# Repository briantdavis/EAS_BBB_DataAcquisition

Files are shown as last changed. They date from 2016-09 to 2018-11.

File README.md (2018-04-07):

# EagleAeroSport BeagleBone Black
# Data Acquisition System

This REPO is intended to be extracted into the folder /EAS on the beaglebone black.

Contains code C++ compiled directly on the BBB, using the debian GCC tool chain.

Key files:<br>
PCA9544 - I2C Mux<br>
ADXL345 - I2C 3-axis Accelerometer<br>
BME280  - I2C Pressure, Humidity & Temperature<br>
MPU6050 - I2C 3-axis Accelerometer & 3-axis Gyro<br>
hscPress- AMSYS AMS59xx series pressure sensors<br>

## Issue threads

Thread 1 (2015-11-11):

Improve Timestamp

briantdavis, 2015-11-11:
The current Timestamp is very coarse timing - using the clock_t structure & clock() function.
Improve the timestamp - sample code from NCAR capstone project.

jcstrang-edu, 2016-02-04:
I didnt see any obvious time reference in the code, so I made a pull with a small file that gets realtime in nanoseconds.

(See Pull Request)

I cannot tell if it will be anyfaster than the "clock_t structure & clock() fucntion", but I m hopeful none the less

My device reads about 3 microSeconds per loop. (doing nothing else)

jcstrang-edu, 2016-02-08:
As we discussed, we will want to look into the specifics of the "CLOCK_REALTIME" and "CLOCK_MONOTIME" System variable to assess which is more practical for our application.

I wrote a very dirty test script to gather the maximum, minimum, and averages for both calls.
What I see is that they're largely the same having a maximum value of 1 second to a minimum of -1 second. I'm not sure if that is simply the nature of the clock or if that is an error on my part, we can look at it in greater detail at the next meeting.

briantdavis, 2016-02-10:
A dual timestamp is implemented in commit #53.

The output in daqPack >> operator is still not human readable.

Hopefully a single timestamp option will prove functional & reduce computation / jitter.

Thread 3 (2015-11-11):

Calibration

briantdavis, 2015-11-11:
Currently, for many sensors, raw values are reported.
There are commonly calibration values provided with sensors; at this point the known issues are

MPU6050 - Temperature, Accel & Gyro
BMP180 - Temperature & Pressure
HSC Press - Pressure & Temperature

These can be addressed incrementally & in parallel.

ee-eas-erau, 2017-11-13:
Can the calibration be in part a of the file with the information formatted as

Calibration coefficient : {DATA}

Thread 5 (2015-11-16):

I2C operating at 400KHz

briantdavis, 2015-11-16:
It is desirable to have both I2C busses operating at 400kHz.

I have been able to get I2C2 operating at 400kHz, but I need to document how this was done so as not to forget.

I have been unable to get I2C1 operating faster than 100kHz - this is an open issue.

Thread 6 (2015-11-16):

Run scripts automatically at boot time

briantdavis, 2015-11-16:
At the moment I need to run the "Enable_i2c" script as root each time I power-on the BBB to enable I2C2.

It would be advantageous to develop a location / script which is automatically executed as root upon power-on so that we can (for now) configure the board, for example Enable I2C2.

Eventually, we will want the DAQ application to automatically run upon power-up, so this will be essential for the flying article.

jcstrang-edu, 2016-02-04:
I have successfully run some test initalization scripts, please see the most recent pull request.

As of now, It does no more than stated.

I have verified its functionality through a boot, however please note that I do not manage any possible errors during initialization.

I imagine that I could get the "Enable I2C" script working for the next commit.

jcstrang-edu, 2016-02-05:
The script now searches for and runs "Enable_third_i2c.sh"

However, I recently noticed that this script actually executes during startup AND shutdown which could be bad in its current form. I have started looking into it, but I may have some trouble understanding it.

jcstrang-edu, 2016-02-06:
So, the entire issue was the fact that I had a bad directory call in my init script, for details, see pull request 12.

It should work as intended.

It doesn't handle errors, but is that a concern with init scripts?

testenv to be deleted next commit

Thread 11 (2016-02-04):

Auto-Detecting Sensors

jcstrang-edu, 2016-02-04:
As discussed, we want a script that can automatically detect, identify and connect to any attached sensors.

This requires the names (OR a data sheet link!) of every device we plan on connecting to the BBB 4G.

briantdavis, 2016-02-04:
Does not need to be a "script" - I was envisioning this as a component / function within the data acquisition executable.  Could be done either way, but I think it would be easier as a single executable to maintain the data structures.

I have an Exel file (also on T: drive) which lists MOST of the I2C addresses that the auto-detect would be required to identify.  I think the best way to identify the sensors is not by name, but by I2C address.

jcstrang-edu, 2016-02-08:
I will look into it. I can see a slight issue when it comes to auto instantiating, which lies in the fact that I enable the third I2c before anything else in the boot script. I am not entirely sure if enabling the I2c communication will inhibit our ability to use those pins for other IO functions. If it doesn't inhibit anything, then there should be no issues coding an sensor auto-detector (that I foresee).

jcstrang-edu, 2016-02-09:
As discussed in the meeting during Feb 8th, 2016,

The Enable 3rd I2c script will need to be run prior to any sensor auto detect code.

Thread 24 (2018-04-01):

hscpress Sensor Data does not match current log files on network drive

Marsfan, 2018-04-01:
The HSC Press sensor is listed in the eas_daq_pack.h file as being a struct with one u8int_t and two u16int_t variables, for a total of 5 bytes

However, examination of the provided log files shows data that totals 6 bytes. An example of this is the first packet, which is listed as having a data section comprising of '00 00 48 31 DF 02'

The log files were likely made with a different version of the source code. Could I get some information regarding this, confirming the correct file size?

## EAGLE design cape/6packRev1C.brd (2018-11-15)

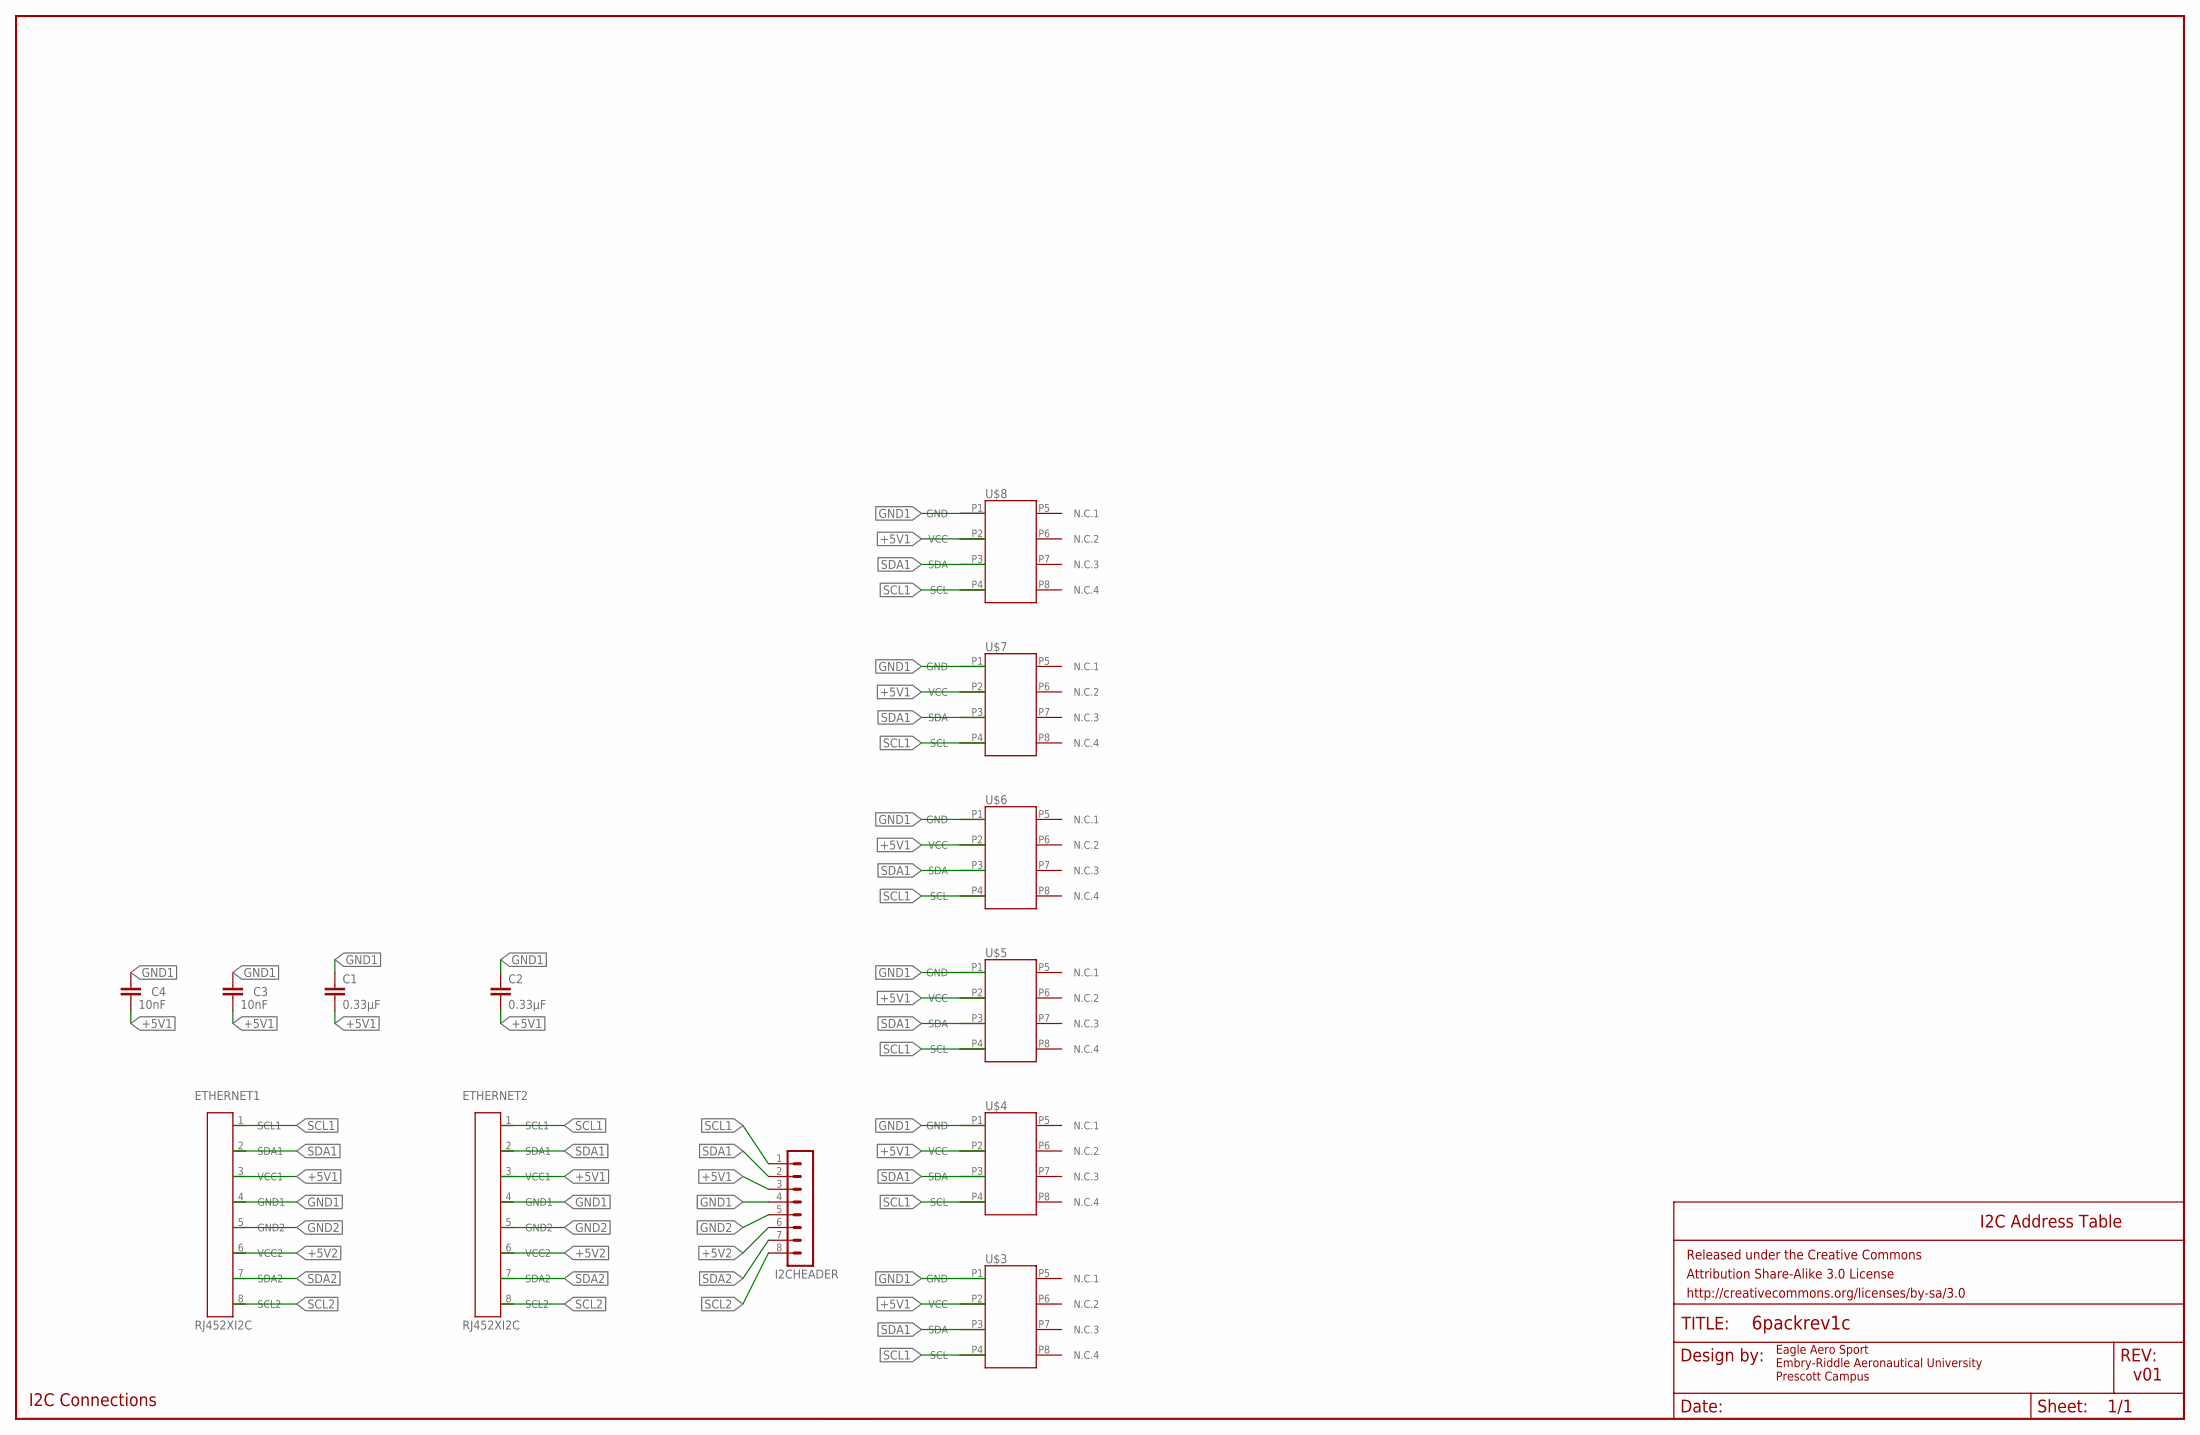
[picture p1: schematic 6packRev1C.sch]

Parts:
C1, C2: 0.33µF; 0805
C3, C4: 10nF; CAP-PTH-10MM
ETHERNET1, ETHERNET2: RJ452XI2C; RJ45-8
FRAME1: FRAME-LEDGER; CREATIVE_COMMONS
I2CHEADER: MA08-1
U$3, U$4, U$5, U$6, U$7, U$8: AMS5915; DIP8W

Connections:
+5V1: C1.2, C2.2, C3.2, C4.2, ETHERNET1.3 (VCC1), ETHERNET2.3 (VCC1), I2CHEADER.3, U$3.P2 (VCC), U$4.P2 (VCC), U$5.P2 (VCC), U$6.P2 (VCC), U$7.P2 (VCC), U$8.P2 (VCC)
+5V2: ETHERNET1.6 (VCC2), ETHERNET2.6 (VCC2), I2CHEADER.6
GND1: C1.1, C2.1, C3.1, C4.1, ETHERNET1.4 (GND1), ETHERNET2.4 (GND1), I2CHEADER.4, U$3.P1 (GND), U$4.P1 (GND), U$5.P1 (GND), U$6.P1 (GND), U$7.P1 (GND), U$8.P1 (GND)
GND2: ETHERNET1.5 (GND2), ETHERNET2.5 (GND2), I2CHEADER.5
SCL1: ETHERNET1.1 (SCL1), ETHERNET2.1 (SCL1), I2CHEADER.1, U$3.P4 (SCL), U$4.P4 (SCL), U$5.P4 (SCL), U$6.P4 (SCL), U$7.P4 (SCL), U$8.P4 (SCL)
SCL2: ETHERNET1.8 (SCL2), ETHERNET2.8 (SCL2), I2CHEADER.8
SDA1: ETHERNET1.2 (SDA1), ETHERNET2.2 (SDA1), I2CHEADER.2, U$3.P3 (SDA), U$4.P3 (SDA), U$5.P3 (SDA), U$6.P3 (SDA), U$7.P3 (SDA), U$8.P3 (SDA)
SDA2: ETHERNET1.7 (SDA2), ETHERNET2.7 (SDA2), I2CHEADER.7

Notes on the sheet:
I2C Address Table
v01
Eagle Aero Sport Embry-Riddle Aeronautical University Prescott Campus
I2C Connections

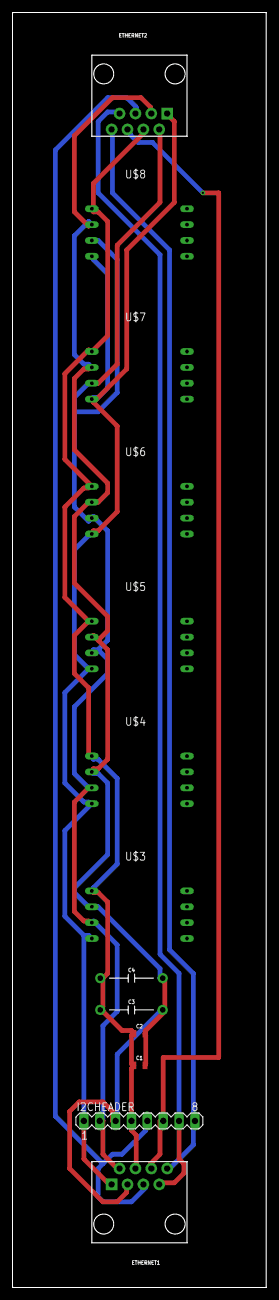
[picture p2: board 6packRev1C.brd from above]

Board: 2 copper layers, 40.6 x 204.1 mm, 14 parts (0 on the bottom side), 8 nets.

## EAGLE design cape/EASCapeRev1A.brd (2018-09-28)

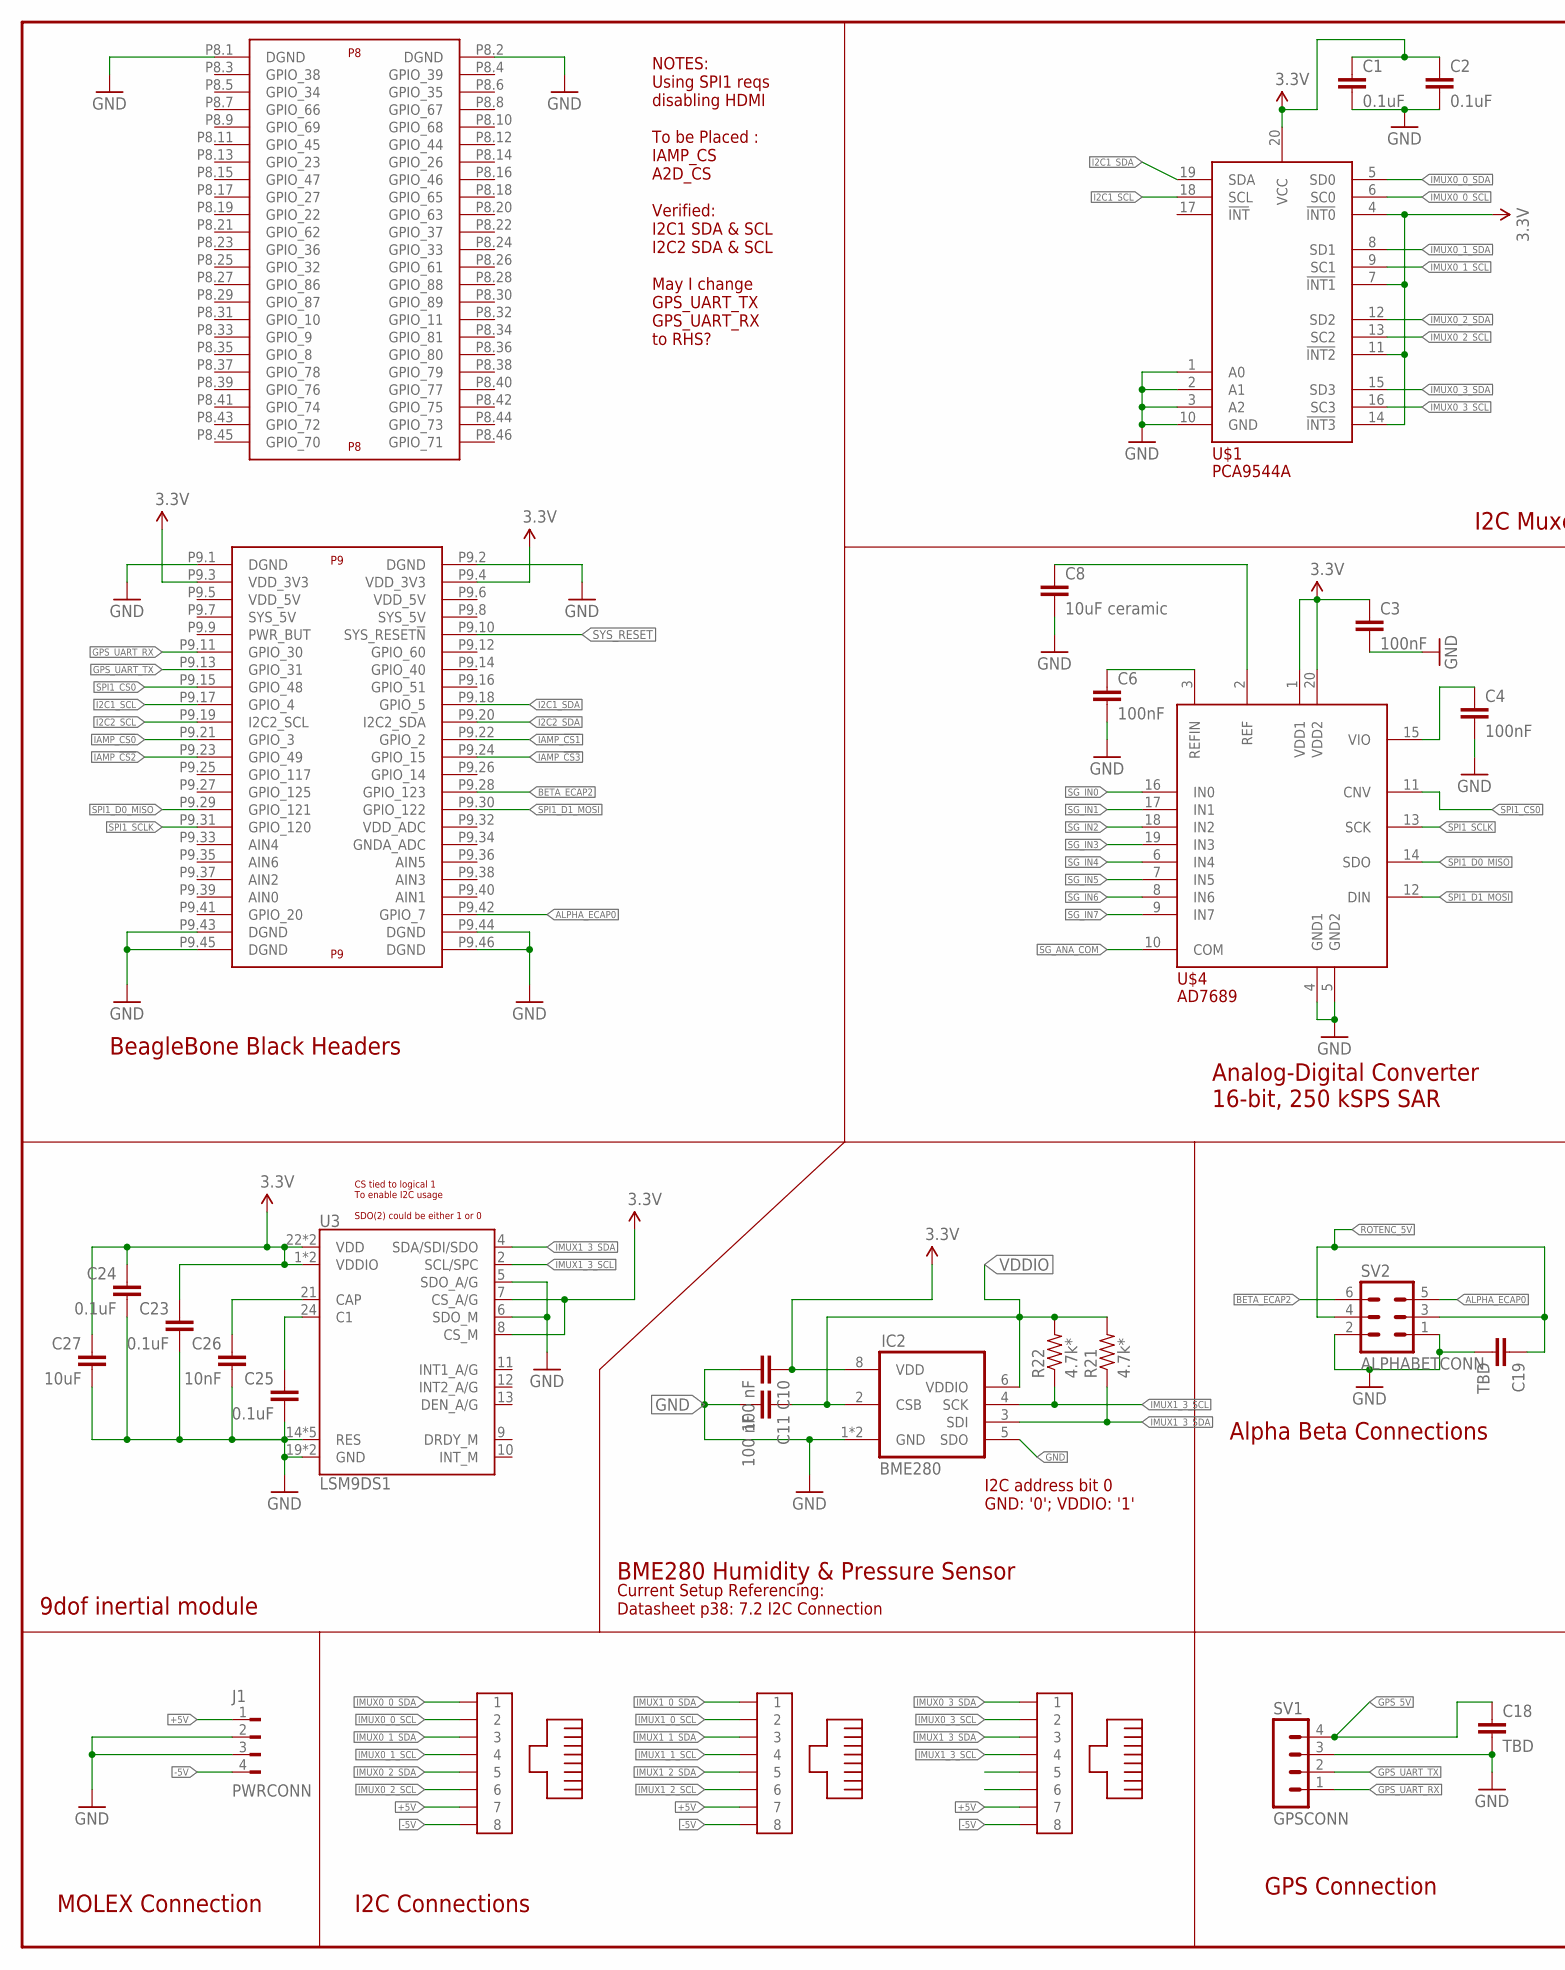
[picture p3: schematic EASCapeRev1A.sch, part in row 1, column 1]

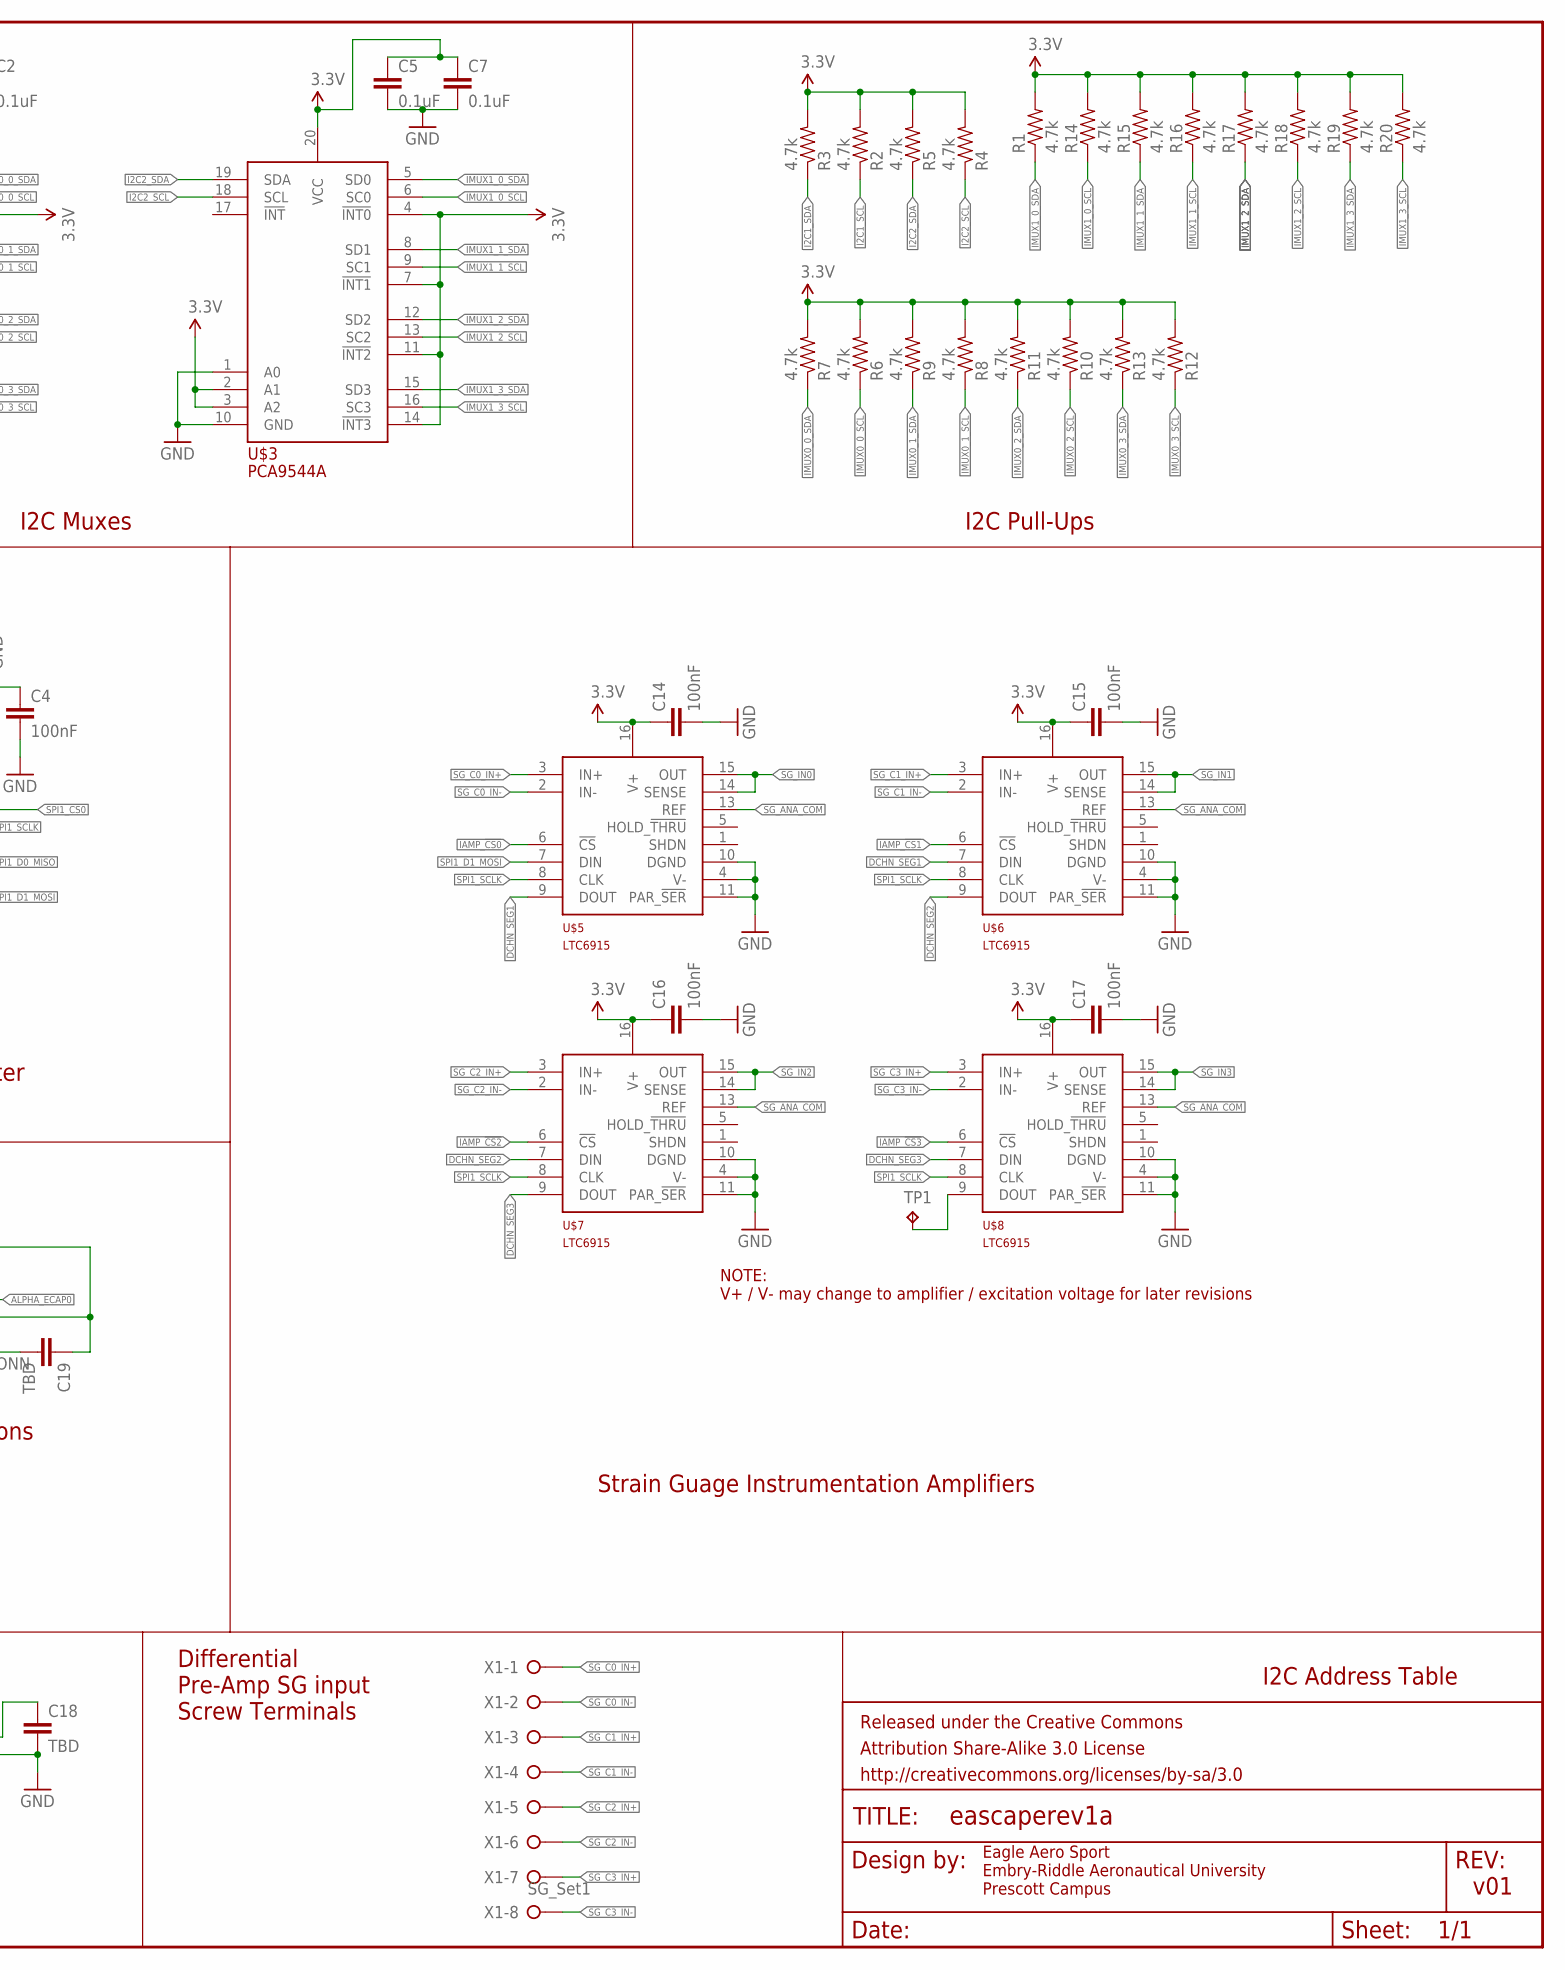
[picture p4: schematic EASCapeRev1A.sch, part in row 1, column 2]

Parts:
C1, C2, C5, C7, C23, C24, C25: 0.1uF; 0805
C3, C4, C6, C14, C15, C16, C17: 100nF; 0805
C8: 10uF ceramic; 0805
C10, C11: 100 nF; 0805
C18, C19: TBD; 0805
C26: 10nF; 0805
C27: 10uF; 0805
FRAME1: FRAME-LEDGER; CREATIVE_COMMONS
IC2: BME280
J1: PWRCONN; 350211
R1, R2, R3, R4, R5, R6, R7, R8, R9, R10, R11, R12, R13, R14, R15, R16, R17, R18, R19, R20: 4.7k; 0805
R21, R22: 4.7k*; 0805
RJ1, RJ2, RJ3: MOLEX-RJ45-SMT
SV1: GPSCONN; MA04-1
SV2: ALPHABETCONN; MA03-2
TP1: TPTP08R; TP08R
U3: LSM9DS1; LGA24-8X4
U$1, U$3: PCA9544A; TSSOP20
U$2: BEAGLE_BONE_BLACK_CAPE
U$4: AD7689; QFN20
U$5, U$6, U$7, U$8: LTC6915; SSOP16
X1: SG_Set1; W237-8P

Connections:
3.3V: C1.1, C2.1, C3.1, C5.1, C7.1, C10.1, C14.1, C15.1, C16.1, C17.1, C23.1, C24.1, C27.1, IC2.8 (VDD), R1.2, R2.2, R3.2, R4.2, R5.2, R6.2, R7.2, R8.2, R9.2, R10.2, R11.2, R12.2, R13.2, R14.2, R15.2, R16.2, R17.2, R18.2, R19.2, R20.2, U3.1 (VDDIO), U3.3 (VDDIO), U3.7 (CS_A/G), U3.8 (CS_M), U3.22 (VDD), U3.23 (VDD), U$1.4 (!INT0!), U$1.7 (!INT1!), U$1.11 (!INT2!), U$1.14 (!INT3!), U$1.20 (VCC), U$2.P9.3 (VDD_3V3), U$2.P9.4 (VDD_3V3), U$3.2 (A1), U$3.3 (A2), U$3.4 (!INT0!), U$3.7 (!INT1!), U$3.11 (!INT2!), U$3.14 (!INT3!), U$3.20 (VCC), U$4.1 (VDD1), U$4.20 (VDD2), U$5.16 (V+), U$6.16 (V+), U$7.16 (V+), U$8.16 (V+)
+5V: J1.1, RJ1.7, RJ2.7, RJ3.7
-5V: J1.4, RJ1.8, RJ2.8, RJ3.8
ALPHA_ECAP0: SV2.5, U$2.P9.42 (GPIO_7)
BETA_ECAP2: SV2.6, U$2.P9.28 (GPIO_123)
C1: C25.1, U3.24 (C1)
CAP: C26.1, U3.21 (CAP)
DCHN_SEG1: U$5.9 (DOUT), U$6.7 (DIN)
DCHN_SEG2: U$6.9 (DOUT), U$7.7 (DIN)
DCHN_SEG3: U$7.9 (DOUT), U$8.7 (DIN)
GND: C1.2, C2.2, C3.2, C4.2, C5.2, C6.2, C7.2, C8.2, C10.2, C11.2, C14.2, C15.2, C16.2, C17.2, C18.2, C19.2, C23.2, C24.2, C25.2, C26.2, C27.2, IC2.1 (GND), IC2.5 (SDO), IC2.7 (GND), J1.2, J1.3, SV1.3, SV2.1, SV2.2, U3.5 (SDO_A/G), U3.6 (SDO_M), U3.14 (RES), U3.15 (RES), U3.16 (RES), U3.17 (RES), U3.18 (RES), U3.19 (GND), U3.20 (GND), U$1.1 (A0), U$1.2 (A1), U$1.3 (A2), U$1.10 (GND), U$2.P8.1 (DGND), U$2.P8.2 (DGND), U$2.P9.1 (DGND), U$2.P9.2 (DGND), U$2.P9.43 (DGND), U$2.P9.44 (DGND), U$2.P9.45 (DGND), U$2.P9.46 (DGND), U$3.1 (A0), U$3.10 (GND), U$4.4 (GND1), U$4.5 (GND2), U$5.4 (V-), U$5.10 (DGND), U$5.11 (PAR_!SER!), U$6.4 (V-), U$6.10 (DGND), U$6.11 (PAR_!SER!), U$7.4 (V-), U$7.10 (DGND), U$7.11 (PAR_!SER!), U$8.4 (V-), U$8.10 (DGND), U$8.11 (PAR_!SER!)
GPS_5V: C18.1, SV1.4
GPS_UART_RX: SV1.1, U$2.P9.11 (GPIO_30)
GPS_UART_TX: SV1.2, U$2.P9.13 (GPIO_31)
I2C1_SCL: R2.1, U$1.18 (SCL), U$2.P9.17 (GPIO_4)
I2C1_SDA: R3.1, U$1.19 (SDA), U$2.P9.18 (GPIO_5)
I2C2_SCL: R4.1, U$2.P9.19 (I2C2_SCL), U$3.18 (SCL)
I2C2_SDA: R5.1, U$2.P9.20 (I2C2_SDA), U$3.19 (SDA)
IAMP_!CS0!: U$2.P9.21 (GPIO_3), U$5.6 (!CS!)
IAMP_!CS1!: U$2.P9.22 (GPIO_2), U$6.6 (!CS!)
IAMP_!CS2!: U$2.P9.23 (GPIO_49), U$7.6 (!CS!)
IAMP_!CS3!: U$2.P9.24 (GPIO_15), U$8.6 (!CS!)
IMUX0_0_SCL: R6.1, RJ1.2, U$1.6 (SC0)
IMUX0_0_SDA: R7.1, RJ1.1, U$1.5 (SD0)
IMUX0_1_SCL: R8.1, RJ1.4, U$1.9 (SC1)
IMUX0_1_SDA: R9.1, RJ1.3, U$1.8 (SD1)
IMUX0_2_SCL: R10.1, RJ1.6, U$1.13 (SC2)
IMUX0_2_SDA: R11.1, RJ1.5, U$1.12 (SD2)
IMUX0_3_SCL: R12.1, RJ3.2, U$1.16 (SC3)
IMUX0_3_SDA: R13.1, RJ3.1, U$1.15 (SD3)
IMUX1_0_SCL: R14.1, RJ2.2, U$3.6 (SC0)
IMUX1_0_SDA: R1.1, RJ2.1, U$3.5 (SD0)
IMUX1_1_SCL: R16.1, RJ2.4, U$3.9 (SC1)
IMUX1_1_SDA: R15.1, RJ2.3, U$3.8 (SD1)
IMUX1_2_SCL: R18.1, RJ2.6, U$3.13 (SC2)
IMUX1_2_SDA: R17.1, RJ2.5, U$3.12 (SD2)
IMUX1_3_SCL: IC2.4 (SCK), R20.1, R22.1, RJ3.4, U3.2 (SCL/SPC), U$3.16 (SC3)
IMUX1_3_SDA: IC2.3 (SDI), R19.1, R21.1, RJ3.3, U3.4 (SDA/SDI/SDO), U$3.15 (SD3)
unnamed: C6.1, U$4.3 (REFIN)
unnamed: C8.1, U$4.2 (REF)
unnamed: C4.1, U$4.15 (VIO)
unnamed: TP1.TP, U$8.9 (DOUT)
ROTENC_5V: C19.1, SV2.3, SV2.4
SG_ANA_COM: U$4.10 (COM), U$5.13 (REF), U$6.13 (REF), U$7.13 (REF), U$8.13 (REF)
SG_C0_IN+: U$5.3 (IN+), X1.1
SG_C0_IN-: U$5.2 (IN-), X1.2
SG_C1_IN+: U$6.3 (IN+), X1.3
SG_C1_IN-: U$6.2 (IN-), X1.4
SG_C2_IN+: U$7.3 (IN+), X1.5
SG_C2_IN-: U$7.2 (IN-), X1.6
SG_C3_IN+: U$8.3 (IN+), X1.7
SG_C3_IN-: U$8.2 (IN-), X1.8
SG_IN0: U$4.16 (IN0), U$5.14 (SENSE), U$5.15 (OUT)
SG_IN1: U$4.17 (IN1), U$6.14 (SENSE), U$6.15 (OUT)
SG_IN2: U$4.18 (IN2), U$7.14 (SENSE), U$7.15 (OUT)
SG_IN3: U$4.19 (IN3), U$8.14 (SENSE), U$8.15 (OUT)
SG_IN4: U$4.6 (IN4)
SG_IN5: U$4.7 (IN5)
SG_IN6: U$4.8 (IN6)
SG_IN7: U$4.9 (IN7)
SPI1_CS0: U$2.P9.15 (GPIO_48), U$4.11 (CNV)
SPI1_D0_MISO: U$2.P9.29 (GPIO_121), U$4.14 (SDO)
SPI1_D1_MOSI: U$2.P9.30 (GPIO_122), U$4.12 (DIN), U$5.7 (DIN)
SPI1_SCLK: U$2.P9.31 (GPIO_120), U$4.13 (SCK), U$5.8 (CLK), U$6.8 (CLK), U$7.8 (CLK), U$8.8 (CLK)
SYS_RESET: U$2.P9.10 (SYS_RESET!N)
VDDIO: C11.1, IC2.2 (CSB), IC2.6 (VDDIO), R21.2, R22.2

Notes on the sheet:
BeagleBone Black Headers
I2C Address Table
v01
Eagle Aero Sport Embry-Riddle Aeronautical University Prescott Campus
I2C Muxes
Analog-Digital Converter 16-bit, 250 kSPS SAR
CS tied to logical 1 To enable I2C usage SDO(2) could be either 1 or 0
9dof inertial module
Strain Guage Instrumentation Amplifiers
Differential Pre-Amp SG input Screw Terminals
I2C Pull-Ups
I2C Connections
NOTES: Using SPI1 reqs disabling HDMI To be Placed : IAMP_CS A2D_CS Verified: I2C1 SDA & SCL I2C2 SDA & SCL May I change GPS_UART_TX GPS_UART_RX to RHS?
NOTE: V+ / V- may change to amplifier / excitation voltage for later revisions
GPS Connection
Alpha Beta Connections
MOLEX Connection
BME280 Humidity & Pressure Sensor
Current Setup Referencing: Datasheet p38: 7.2 I2C Connection
I2C address bit 0 GND: '0'; VDDIO: '1'

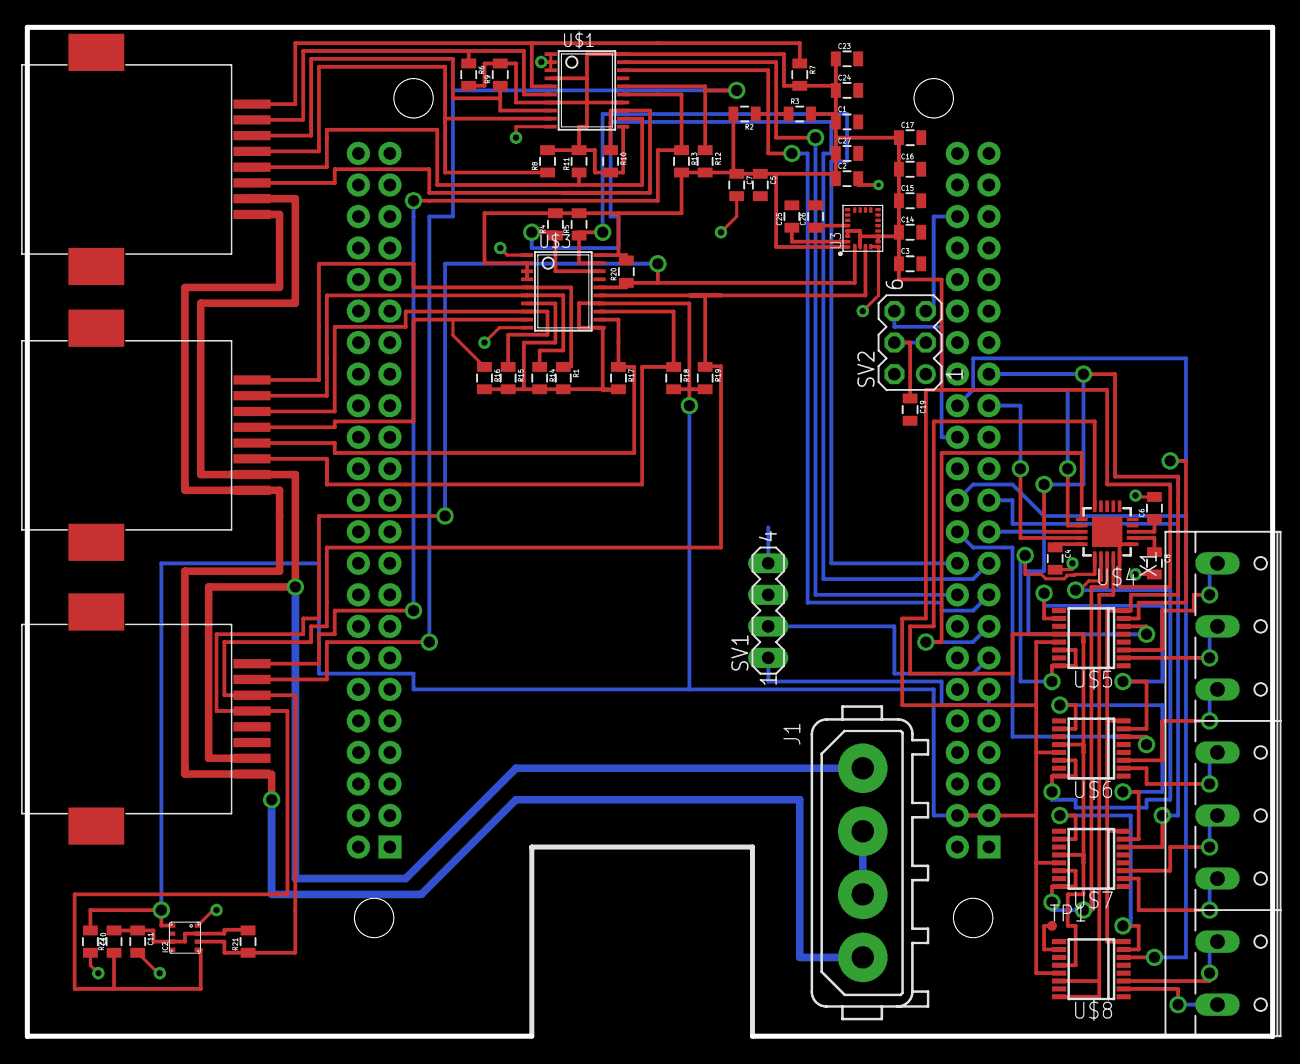
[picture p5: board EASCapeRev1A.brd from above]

Board: 2 copper layers, 100.3 x 81.3 mm, 62 parts (1 on the bottom side), 61 nets.

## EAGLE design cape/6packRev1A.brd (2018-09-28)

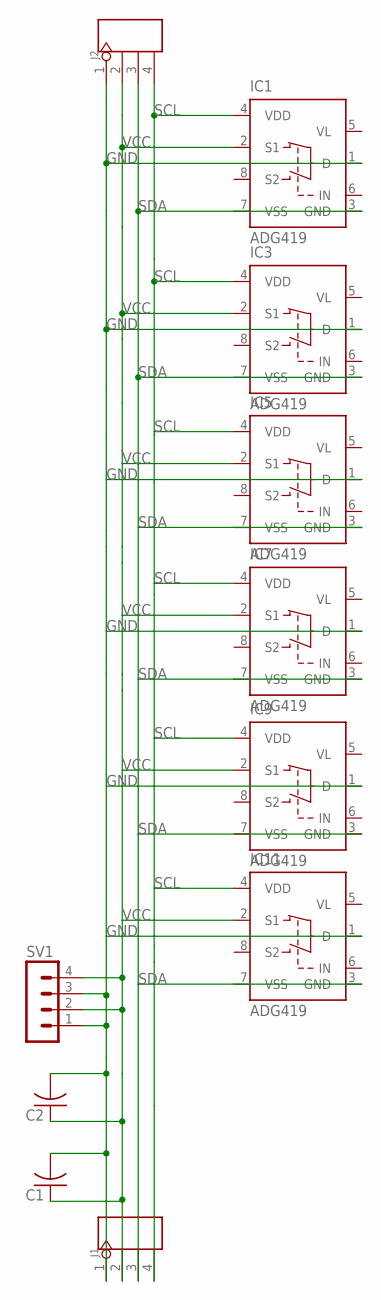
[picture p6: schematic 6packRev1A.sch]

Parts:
C1, C2: C-USC0805; C0805
IC1, IC3, IC5, IC7, IC9, IC11: ADG419; DIL08
J1, J2: HEADER-4P-80/40MIL; 4P-2.54-80/40MIL
SV1: MA04-1

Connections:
GND: C1.2, C2.2, IC1.1 (D), IC3.1 (D), IC5.1 (D), IC7.1 (D), IC9.1 (D), IC11.1 (D), J1.1, J2.1, SV1.1, SV1.3
SCL: IC1.4 (VDD), IC3.4 (VDD), IC5.4 (VDD), IC7.4 (VDD), IC9.4 (VDD), IC11.4 (VDD), J1.4, J2.4
SDA: IC1.3 (GND), IC1.7 (VSS), IC3.3 (GND), IC3.7 (VSS), IC5.3 (GND), IC5.7 (VSS), IC7.3 (GND), IC7.7 (VSS), IC9.3 (GND), IC11.3 (GND), J1.3, J2.3
VCC: C1.1, C2.1, IC1.2 (S1), IC3.2 (S1), IC5.2 (S1), IC7.2 (S1), IC9.2 (S1), IC11.2 (S1), J1.2, J2.2, SV1.2, SV1.4
VL: IC1.5 (VL), IC3.5 (VL), IC5.5 (VL), IC7.5 (VL), IC9.5 (VL), IC11.5 (VL)
VSS: IC9.7 (VSS), IC11.7 (VSS)

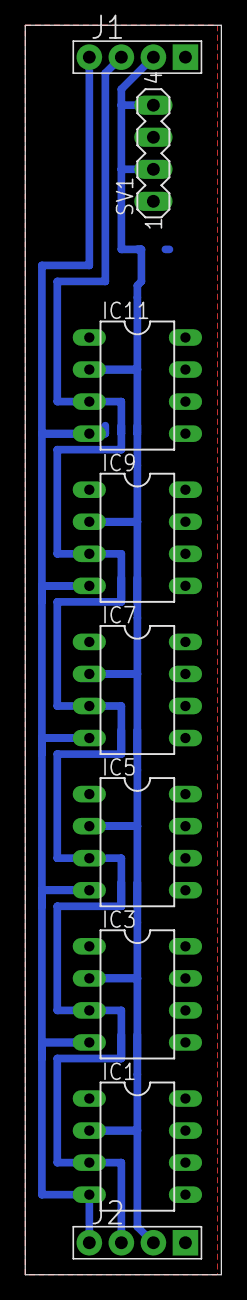
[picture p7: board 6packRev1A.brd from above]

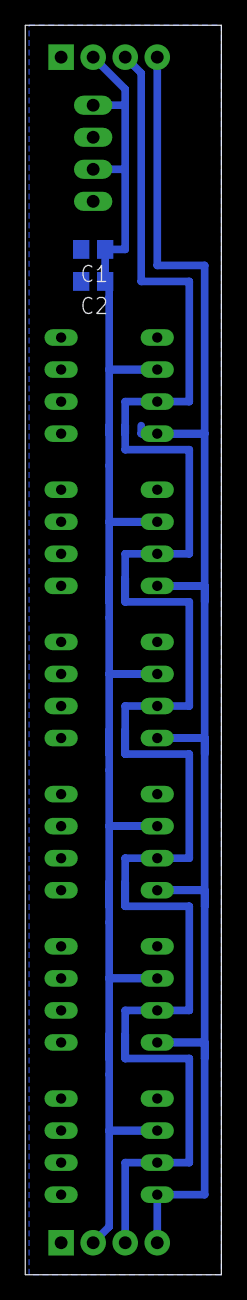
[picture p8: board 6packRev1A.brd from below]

Board: 2 copper layers, 15.5 x 99.0 mm, 11 parts (2 on the bottom side), 6 nets.

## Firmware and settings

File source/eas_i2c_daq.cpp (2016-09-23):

<<<<<<< HEAD
//
// EAS
//
// Brian Davis
//
// I2C development Code

//
// ANSI C includes
//
#include <errno.h>
#include <string.h>
#include <stdio.h>
#include <stdlib.h>
// #include <unistd.h>  Old Ansi C / linux threads
#include <linux/i2c-dev.h>
#include <sys/ioctl.h>
#include <sys/types.h>
#include <sys/stat.h>
#include <sys/mman.h>         // Shared Memory mmap/munmap
#include <fcntl.h>
#include <sys/wait.h>         // waitpid

//
// C++ includes
//
#include <iostream>
#include <istream>
#include <fstream>

//
// Project specific includes
//
#include "libs/tc/tinycon.h"

#include "eas_daq_pack.h"

#include "bmp180_bosch.h"
#include "ADXL345Accelerometer.h"
#include "bmp180.h"
#include "bme280.h"
#include "pca9544mux.h"
#include "mpu6050AccelGyro.h"
#include "hscPress.h"  

// -------------------------------------------
//
// #define
//
// Application / DAQ
//
#define ITTER_LOOP_PAUSE     1E5
#define MIN_ILOOP            500
#define DISP_INTERVAL        1

//
// I2C Space
//

#define I2C_HW1_BUS_NUM    2
#define I2C_HW2_BUS_NUM    1

//
// Types
// 

typedef struct shared_vars {
  bool gDone;
  bool gDispEnabled;
  bool gLogFileEnabled;
  unsigned int iLoopPause;
    uint8_t      gNextUniqueID;
} shared_vars_t;

//
// Globals
//

volatile static shared_vars_t *sv;

//
// Prototypes
//

int block_children_shutdown(int);

//---------------------------------------------------
// #includes which require sv structure defn
//
#include "eas_tcon.h"


//---------------------------------------------------
//
// Main()
//
int main(int argc, char* argv[])
{
  uint8_t timeStamp_UID;
  std::ofstream logFileStream;
  //----------------------------
  // ***
  // Set up shared memory space
  //
  sv = (shared_vars_t *) mmap(NULL, sizeof(shared_vars_t), PROT_READ | PROT_WRITE, 
                             MAP_SHARED | MAP_ANONYMOUS, -1, 0);
  sv->gDone = false;
  sv->gDispEnabled = true;
  sv->gLogFileEnabled = true;
  sv->iLoopPause = ITTER_LOOP_PAUSE;
  sv->gNextUniqueID = 0;
  timeStamp_UID = (++sv->gNextUniqueID);
  
  // ***
  // Sensor Object creation
  //
  // This section will be eliminated when sensor auto-detect
  // is written & operational
  //
  
  // I2C ONE
  //  bmp180 baroSen(I2C_HW1_BUS_NUM, ++sv->gNextUniqueID);
  BME280 humPress1(I2C_HW1_BUS_NUM, BME280_SDO_L_ADDR, ++sv->gNextUniqueID);

  //
  // I2C TWO
  PCA9544Mux i2cMuxNum1(I2C_HW2_BUS_NUM, PCA9544_000_ADDR);
  i2cMuxNum1.selectChan(PCA9544Mux :: CH_0);
  
  ADXL345Accelerometer accelNum1(I2C_HW2_BUS_NUM, ADXL345_SDO_L_ADDR, ++sv->gNextUniqueID);
  ADXL345Accelerometer accelNum2(I2C_HW2_BUS_NUM, ADXL345_SDO_H_ADDR, ++sv->gNextUniqueID);

  i2cMuxNum1.selectChan(PCA9544Mux :: CH_3);
  ADXL345Accelerometer accelNum3(I2C_HW2_BUS_NUM, ADXL345_SDO_H_ADDR, ++sv->gNextUniqueID);
  HscPress pressNum1(I2C_HW2_BUS_NUM, HSC_PN2_ADDR, ++sv->gNextUniqueID);
  
  
  // MPU6050AccelGyro accGyrNum3(I2C_HW2_BUS_NUM, MPU6050_AD0_L_ADDR);
  /*  
  HscPress pressNum1(I2C_HW2_BUS_NUM, HSC_PN2_ADDR);
  ADXL345Accelerometer accelNum2(I2C_HW2_BUS_NUM, ADXL345_SDO_L_ADDR);
  i2cMuxNum1.selectChan(PCA9544Mux :: CH_2);
  ADXL345Accelerometer accelNum4(I2C_HW2_BUS_NUM, ADXL345_SDO_H_ADDR);
  i2cMuxNum1.selectChan(PCA9544Mux :: CH_3);
  ADXL345Accelerometer accelNum5(I2C_HW2_BUS_NUM, ADXL345_SDO_H_ADDR);
  ADXL345Accelerometer accelNum6(I2C_HW2_BUS_NUM, ADXL345_SDO_L_ADDR);
  */

  // ***
  // Open Log File
  //
  if (sv->gLogFileEnabled)
  {
    #define LOG_NAME_SZ 120
    time_t now;
    char log_name[LOG_NAME_SZ] = {0};
    // -------------
    now = time(NULL);
    if (now == -1)
    {
      // ERROR HANDLING: you can check  to see what went wrong 
      perror("Failed to acquire date string for file in main");
      exit(1);
    }
    //-----
    strftime(log_name, LOG_NAME_SZ, "/EAS/logs/easRV12_%d_%b_%Y_%H_%M_%S.log", 
      gmtime(&now));
    logFileStream.open(log_name, std::ofstream::out | std::ofstream::app);
    if (!logFileStream.good())
    {
      // ERROR HANDLING
      perror("Failed to open the logfile in main");
      std::cout << "Log File Name = " << log_name << std::endl;
      std::cout << "Errno = " << logFileStream << std::endl;
      std::cout << "Typical Cause - Log file directory does not exist" << std::endl;
      exit(1);
    }
    std::cout << std::endl << "Log File " << log_name << " opened." << std::endl;
  } // if enabled


  //
  // @@@ TODO:
  // Autodetect I2C sensors
  // Read Config file for installed non-I2C sensors
  // Write insalled sensors list to Log-File
  // located HERE!
  
  humPress1.logPartASensorID(logFileStream, "On Cape");
  i2cMuxNum1.logPartASensorID(logFileStream);
  accelNum1.logPartASensorID(logFileStream, "On Proto (0) RH Orientation");
  accelNum2.logPartASensorID(logFileStream, "On Proto (0) LH Orientation");
  accelNum3.logPartASensorID(logFileStream, "On Proto (1)");
  pressNum1.logPartASensorID(logFileStream, "On Proto (1) atmospheric differential");
  
  //
  // @@@ TODO:
  // Read Cal Data from all Sensors & Write to Log-File
  // located HERE!




  // logFileStream.seekp(2048);
  
  while (logFileStream.tellp() < 0x800)
  {
    char buf[10] = {0};
    logFileStream.write(buf,1);
  }
  
  
  if (!logFileStream.good())
  {
     std::cout << std::endl << "LogFile Seek() error."<< std::endl;
    return 0;
  }

  //
  // Setup TinyCon in Parallel Thread
  // To accept Input from console
  // Quit / Increase speed / Decrease speed
  // Diasble 
  // 
  int tc_pid = fork();
  if (tc_pid == 0)
  {
    tcon tc(std::string(""));
    tc.run();
    std::cout << std::endl << "TinyCom thread ShutDown."<< std::endl;
    return 0;
  }




  //
  // Begin Repeated DAQ Loop
  // This will later be MULTI-Threaded
  // For each unique BUS {I2C1, I2C2, SPI, UART, etc..}
  //
  while (!sv->gDone)
  {
    clock_t t_c;
    struct timespec t_p; 
    EasDAQpack curPack[20];
    int pack_i = 0;
    static unsigned int frc;    
    //------------------------
    //
    // Timestamp
    t_c = clock();
    clock_gettime(CLOCK_REALTIME, &t_p);
    curPack[pack_i++].setClockDual(t_c, t_p, timeStamp_UID);
    
    if (frc % 5 == 0)
    {    
     //
     // Pressure, Humidity  & Temperature
     //    
      humPress1.updateHumidPressTemp();
      humPress1.fillEASpack(curPack[pack_i++]);
    }
    
    //
    // Select Channel
    i2cMuxNum1.selectChan(PCA9544Mux :: CH_0);
    
    //
    // Read from ADXL345 Num 1
    //
    accelNum1.updateAccelData();
    accelNum1.fillEASpack(curPack[pack_i++]);
    
    //
    // Read from ADXL345 Num 2
    //
    accelNum2.updateAccelData();
    accelNum2.fillEASpack(curPack[pack_i++]);
    
        //
    // Select Channel
    i2cMuxNum1.selectChan(PCA9544Mux :: CH_3);
    
    //
    // HSC Pressure Sensor
    //
    pressNum1.updatePressTemp();
    pressNum1.fillEASpack(curPack[pack_i++]);

    //
    // Read from ADXL345 Num 3
    //
    accelNum3.updateAccelData();
    accelNum3.fillEASpack(curPack[pack_i++]);
    
    //
    // Read from MPU6050 Num 3
    //
    /*accGyrNum3.updateAccelGyroTempData();
    accGyrNum3.fillEASpack(curPack[pack_i++]);
    */
    /*
    
    //
    // Read from ADXL345 Num 2
    //
    accelNum2.updateAccelData();
    curPack[pack_i].blank();
    accelNum2.fillEASpack(curPack[pack_i++]);
      
    //
    // Read from MPU6050 Num 3
    //
    accGyrNum3.updateAccelGyroTempData();
    curPack[pack_i].blank();
    accGyrNum3.fillEASpack(curPack[pack_i++]);
    
    
    //
    // Select 02
    i2cMuxNum1.selectChan(PCA9544Mux :: CH_2); 
    
    //
    // Read from ADXL345 Num 4
    //
    accelNum4.updateAccelData();
    curPack[pack_i].blank();
    accelNum4.fillEASpack(curPack[pack_i++]);
    
    //
    // Select 03
    i2cMuxNum1.selectChan(PCA9544Mux :: CH_3); 
    
    //
    // Read from ADXL345 Num 5
    //
    accelNum5.updateAccelData();
    curPack[pack_i].blank();
    accelNum5.fillEASpack(curPack[pack_i++]);
          
    //
    // Read from ADXL345 Num 6
    //
    accelNum6.updateAccelData();
    curPack[pack_i].blank();
    accelNum6.fillEASpack(curPack[pack_i++]);
    */
    
 
    //
    // Log Data 
    if (logFileStream.good())
    {
      for (int i = 0; i < pack_i ; i++)
        curPack[i].outToFile(logFileStream);
    }
    
    //
    // Display Data once every DISP_INTERVAL
    //
    if ((sv->gDispEnabled) && ((frc % DISP_INTERVAL) == 0))
    {
       for (int i = 0; i < pack_i ; i++)
       {
         std::cout << curPack[i] << std::endl;
       }
    }
      
    // Pause 
    if (sv->iLoopPause != MIN_ILOOP)
      usleep(sv->iLoopPause);
      
      
    //
    // Clear Used Data Packs
    for (int i = 0; i < pack_i ; i++)
      curPack[pack_i].blank();
    
    //
    // Increment FRC
    frc++;
  } // while
  
  //
  // Parent thread should make sure all children close first
  block_children_shutdown(tc_pid);
  
  //
  // Close Log File
  if (logFileStream.good())
  {
    std::cout << "  Closing Log File" << std::endl;
    logFileStream.close();
  }
  
  //
  // Free shared memory space
  munmap((void *)sv, sizeof(shared_vars_t));
  
  std::cout << "    Exiting Primary Thread Normally..." << std::endl;
  return 0;
} // main

// *****************************************************
// Wait for Children to close
//
int block_children_shutdown(int pid0)
{
// ***
  // For clean shutdown, make sure child processes close first.
  //
  // http://stackoverflow.com/questions/5057137/c-loop-while-child-is-alive
  int Stat;
  // Blocking while()
  while (waitpid(pid0, &Stat, WNOHANG) != pid0);
  if (WIFEXITED(Stat)) {
    std::cout << "  parent: Child exited with exit code " << WEXITSTATUS(Stat) << std::endl;
  } else if (WIFSIGNALED(Stat)) {
    std::cout << "  parent: Child killed with signal " << WTERMSIG(Stat) << std::endl;
  } else {
    std::cout << "  parent: Something else happened to child, e.g. STOPPED" << std::endl;
  }
  return(Stat);
}
=======
//
// EAS
//
// Brian Davis
//
// I2C development Code

//
// ANSI C includes
//
#include <errno.h>
#include <string.h>
#include <stdio.h>
#include <stdlib.h>
// #include <unistd.h>  Old Ansi C / linux threads
#include <linux/i2c-dev.h>
#include <sys/ioctl.h>
#include <sys/types.h>
#include <sys/stat.h>
#include <sys/mman.h>         // Shared Memory mmap/munmap
#include <fcntl.h>
#include <sys/wait.h>         // waitpid

//
// C++ includes
//
#include <iostream>
#include <istream>
#include <fstream>

//
// Project specific includes
//
#include "libs/tc/tinycon.h"

#include "eas_daq_pack.h"

#include "bmp180_bosch.h"
#include "ADXL345Accelerometer.h"
#include "bmp180.h"
#include "bme280.h"
#include "pca9544mux.h"
#include "mpu6050AccelGyro.h"
#include "hscPress.h"  

// -------------------------------------------
//
// #define
//
// Application / DAQ
//
#define ITTER_LOOP_PAUSE     1E5
#define MIN_ILOOP            500
#define DISP_INTERVAL        1

//
// I2C Space
//

#define I2C_HW1_BUS_NUM    2
#define I2C_HW2_BUS_NUM    1

//
// Types
// 

typedef struct shared_vars {
  bool gDone;
  bool gDispEnabled;
  bool gLogFileEnabled;
  unsigned int iLoopPause;
    uint8_t      gNextUniqueID;
} shared_vars_t;

//
// Globals
//

volatile static shared_vars_t *sv;

//
// Prototypes
//

int block_children_shutdown(int);

//---------------------------------------------------
// #includes which require sv structure defn
//
#include "eas_tcon.h"


//---------------------------------------------------
//
// Main()
//
int main(int argc, char* argv[])
{
  uint8_t timeStamp_UID;
  std::ofstream logFileStream;
  //----------------------------
  // ***
  // Set up shared memory space
  //
  sv = (shared_vars_t *) mmap(NULL, sizeof(shared_vars_t), PROT_READ | PROT_WRITE, 
                             MAP_SHARED | MAP_ANONYMOUS, -1, 0);
  sv->gDone = false;
  sv->gDispEnabled = true;
  sv->gLogFileEnabled = true;
  sv->iLoopPause = ITTER_LOOP_PAUSE;
  sv->gNextUniqueID = 0;
  timeStamp_UID = (++sv->gNextUniqueID);
  
  // ***
  // Sensor Object creation
  //
  // This section will be eliminated when sensor auto-detect
  // is written & operational
  //
  
  // I2C ONE
  //  bmp180 baroSen(I2C_HW1_BUS_NUM, ++sv->gNextUniqueID);
  BME280 humPress1(I2C_HW1_BUS_NUM, BME280_SDO_L_ADDR, ++sv->gNextUniqueID);

  //
  // I2C TWO
  PCA9544Mux i2cMuxNum1(I2C_HW2_BUS_NUM, PCA9544_000_ADDR);
  i2cMuxNum1.selectChan(PCA9544Mux :: CH_3);
  
  ADXL345Accelerometer accelNum1(I2C_HW2_BUS_NUM, ADXL345_SDO_L_ADDR, ++sv->gNextUniqueID);
  ADXL345Accelerometer accelNum2(I2C_HW2_BUS_NUM, ADXL345_SDO_H_ADDR, ++sv->gNextUniqueID);
  HscPress pressNum1(I2C_HW2_BUS_NUM, HSC_PN2_ADDR, ++sv->gNextUniqueID);
  
  // MPU6050AccelGyro accGyrNum3(I2C_HW2_BUS_NUM, MPU6050_AD0_L_ADDR);
  /*  
  
  ADXL345Accelerometer accelNum2(I2C_HW2_BUS_NUM, ADXL345_SDO_L_ADDR);
  i2cMuxNum1.selectChan(PCA9544Mux :: CH_2);
  ADXL345Accelerometer accelNum4(I2C_HW2_BUS_NUM, ADXL345_SDO_H_ADDR);
  i2cMuxNum1.selectChan(PCA9544Mux :: CH_3);
  ADXL345Accelerometer accelNum5(I2C_HW2_BUS_NUM, ADXL345_SDO_H_ADDR);
  ADXL345Accelerometer accelNum6(I2C_HW2_BUS_NUM, ADXL345_SDO_L_ADDR);
  */

  // ***
  // Open Log File
  //
  if (sv->gLogFileEnabled)
  {
    #define LOG_NAME_SZ 120
    time_t now;
    char log_name[LOG_NAME_SZ] = {0};
    // -------------
    now = time(NULL);
    if (now == -1)
    {
      // ERROR HANDLING: you can check  to see what went wrong 
      perror("Failed to acquire date string for file in main");
      exit(1);
    }
    //-----
    strftime(log_name, LOG_NAME_SZ, "/EAS/logs/easRV12_%d_%b_%Y_%H_%M_%S.log", 
      gmtime(&now));
    logFileStream.open(log_name, std::ofstream::out | std::ofstream::app);
    if (!logFileStream.good())
    {
      // ERROR HANDLING
      perror("Failed to open the logfile in main");
      std::cout << "Log File Name = " << log_name << std::endl;
      std::cout << "Errno = " << logFileStream << std::endl;
      std::cout << "Typical Cause - Log file directory does not exist" << std::endl;
      exit(1);
    }
    std::cout << std::endl << "Log File " << log_name << " opened." << std::endl;
  } // if enabled


  //
  // @@@ TODO:
  // Autodetect I2C sensors
  // Read Config file for installed non-I2C sensors
  // Write insalled sensors list to Log-File
  // located HERE!
  
  humPress1.logPartASensorID(logFileStream, "On Cape");
  i2cMuxNum1.logPartASensorID(logFileStream);
  accelNum1.logPartASensorID(logFileStream, "On Proto RH Orientation");
  accelNum2.logPartASensorID(logFileStream, "On Proto LH Orientation");
  pressNum1.logPartASensorID(logFileStream, "On Proto - atmospheric differential");
  
  //
  // @@@ TODO:
  // Read Cal Data from all Sensors & Write to Log-File
  // located HERE!




  // logFileStream.seekp(2048);
  
  while (logFileStream.tellp() < 0x800)
  {
    char buf[10] = {0};
    logFileStream.write(buf,1);
  }
  
  
  if (!logFileStream.good())
  {
     std::cout << std::endl << "LogFile Seek() error."<< std::endl;
    return 0;
  }

  //
  // Setup TinyCon in Parallel Thread
  // To accept Input from console
  // Quit / Increase speed / Decrease speed
  // Diasble 
  // 
  int tc_pid = fork();
  if (tc_pid == 0)
  {
    tcon tc(std::string(""));
    tc.run();
    std::cout << std::endl << "TinyCom thread ShutDown."<< std::endl;
    return 0;
  }
  
  //
  // @@@ TODO:
  // Read Cal Data from all Sensors & Write to Log-File
  // 
  // located HERE!

  //
  // Begin Repeated DAQ Loop
  // This will later be MULTI-Threaded
  // For each unique BUS {I2C1, I2C2, SPI, UART, etc..}
  //
  while (!sv->gDone)
  {
    clock_t t_c;
    struct timespec t_p; 
    EasDAQpack curPack[20];
    int pack_i = 0;
    static unsigned int frc;    
    //------------------------
    //
    // Timestamp
    t_c = clock();
    clock_gettime(CLOCK_REALTIME, &t_p);
    curPack[pack_i++].setClockDual(t_c, t_p, timeStamp_UID);
    
    if (frc % 5 == 0)
    {    
     //
     // Pressure, Humidity  & Temperature
     //    
      humPress1.updateHumidPressTemp();
      humPress1.fillEASpack(curPack[pack_i++]);
    }
    
    //
    // Select Channel
    i2cMuxNum1.selectChan(PCA9544Mux :: CH_3);
    
    //
    // Read from ADXL345 Num 1
    //
    accelNum1.updateAccelData();
    accelNum1.fillEASpack(curPack[pack_i++]);
    
    //
    // Read from ADXL345 Num 1
    //
    accelNum2.updateAccelData();
    accelNum2.fillEASpack(curPack[pack_i++]);
    
    //
    // HSC Pressure Sensor
    //
    pressNum1.updatePressTemp();
    pressNum1.fillEASpack(curPack[pack_i++]);

    //
    // Read from MPU6050 Num 3
    //
    /*accGyrNum3.updateAccelGyroTempData();
    accGyrNum3.fillEASpack(curPack[pack_i++]);
    */
    /*
    
    //
    // Read from ADXL345 Num 2
    //
    accelNum2.updateAccelData();
    curPack[pack_i].blank();
    accelNum2.fillEASpack(curPack[pack_i++]);
      
    //
    // Read from MPU6050 Num 3
    //
    accGyrNum3.updateAccelGyroTempData();
    curPack[pack_i].blank();
    accGyrNum3.fillEASpack(curPack[pack_i++]);
    
    
    //
    // Select 02
    i2cMuxNum1.selectChan(PCA9544Mux :: CH_2); 
    
    //
    // Read from ADXL345 Num 4
    //
    accelNum4.updateAccelData();
    curPack[pack_i].blank();
    accelNum4.fillEASpack(curPack[pack_i++]);
    
    //
    // Select 03
    i2cMuxNum1.selectChan(PCA9544Mux :: CH_3); 
    
    //
    // Read from ADXL345 Num 5
    //
    accelNum5.updateAccelData();
    curPack[pack_i].blank();
    accelNum5.fillEASpack(curPack[pack_i++]);
          
    //
    // Read from ADXL345 Num 6
    //
    accelNum6.updateAccelData();
    curPack[pack_i].blank();
    accelNum6.fillEASpack(curPack[pack_i++]);
    */
    
 
    //
    // Log Data 
    if (logFileStream.good())
    {
      for (int i = 0; i < pack_i ; i++)
        curPack[i].outToFile(logFileStream);
    }
    
    //
    // Display Data once every DISP_INTERVAL
    //
    if ((sv->gDispEnabled) && ((frc % DISP_INTERVAL) == 0))
    {
       for (int i = 0; i < pack_i ; i++)
       {
         std::cout << curPack[i] << std::endl;
       }
    }
      
    // Pause 
    if (sv->iLoopPause != MIN_ILOOP)
      usleep(sv->iLoopPause);
      
      
    //
    // Clear Used Data Packs
    for (int i = 0; i < pack_i ; i++)
      curPack[pack_i].blank();
    
    //
    // Increment FRC
    frc++;
  } // while
  
  //
  // Parent thread should make sure all children close first
  block_children_shutdown(tc_pid);
  
  //
  // Close Log File
  if (logFileStream.good())
  {
    std::cout << "  Closing Log File" << std::endl;
    logFileStream.close();
  }
  
  //
  // Free shared memory space
  munmap((void *)sv, sizeof(shared_vars_t));
  
  std::cout << "    Exiting Primary Thread Normally..." << std::endl;
  return 0;
} // main

// *****************************************************
// Wait for Children to close
//
int block_children_shutdown(int pid0)
{
// ***
  // For clean shutdown, make sure child processes close first.
  //
  // http://stackoverflow.com/questions/5057137/c-loop-while-child-is-alive
  int Stat;
  // Blocking while()
  while (waitpid(pid0, &Stat, WNOHANG) != pid0);
  if (WIFEXITED(Stat)) {
    std::cout << "  parent: Child exited with exit code " << WEXITSTATUS(Stat) << std::endl;
  } else if (WIFSIGNALED(Stat)) {
    std::cout << "  parent: Child killed with signal " << WTERMSIG(Stat) << std::endl;
  } else {
    std::cout << "  parent: Something else happened to child, e.g. STOPPED" << std::endl;
  }
  return(Stat);
}
>>>>>>> 9bdeb79f0525f66a65b6099bb9db65db708e0349

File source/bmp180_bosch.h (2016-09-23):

/** \mainpage
*
****************************************************************************
* Copyright (C) 2008 - 2015 Bosch Sensortec GmbH
*
* File : bmp180.h
*
* Date : 2015/03/27
*
* Revision : 2.2.2
*
* Usage: Sensor Driver for BMP180 sensor
*
****************************************************************************
*
* \section License
*
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
*   Redistributions of source code must retain the above copyright
*   notice, this list of conditions and the following disclaimer.
*
*   Redistributions in binary form must reproduce the above copyright
*   notice, this list of conditions and the following disclaimer in the
*   documentation and/or other materials provided with the distribution.
*
*   Neither the name of the copyright holder nor the names of the
*   contributors may be used to endorse or promote products derived from
*   this software without specific prior written permission.
*
* THIS SOFTWARE IS PROVIDED BY THE COPYRIGHT HOLDERS AND
* CONTRIBUTORS "AS IS" AND ANY EXPRESS OR
* IMPLIED WARRANTIES, INCLUDING, BUT NOT LIMITED TO, THE IMPLIED
* WARRANTIES OF MERCHANTABILITY AND FITNESS FOR A PARTICULAR PURPOSE ARE
* DISCLAIMED. IN NO EVENT SHALL COPYRIGHT HOLDER
* OR CONTRIBUTORS BE LIABLE FOR ANY
* DIRECT, INDIRECT, INCIDENTAL, SPECIAL, EXEMPLARY,
* OR CONSEQUENTIAL DAMAGES(INCLUDING, BUT NOT LIMITED TO,
* PROCUREMENT OF SUBSTITUTE GOODS OR SERVICES;
* LOSS OF USE, DATA, OR PROFITS; OR BUSINESS INTERRUPTION)
* HOWEVER CAUSED AND ON ANY THEORY OF LIABILITY,
* WHETHER IN CONTRACT, STRICT LIABILITY, OR TORT
* (INCLUDING NEGLIGENCE OR OTHERWISE) ARISING IN
* ANY WAY OUT OF THE USE OF THIS
* SOFTWARE, EVEN IF ADVISED OF THE POSSIBILITY OF SUCH DAMAGE
*
* The information provided is believed to be accurate and reliable.
* The copyright holder assumes no responsibility
* for the consequences of use
* of such information nor for any infringement of patents or
* other rights of third parties which may result from its use.
* No license is granted by implication or otherwise under any patent or
* patent rights of the copyright holder.
**************************************************************************/
 /** \file bmp180.h
    \brief Header file for all define constants and function prototypes
*/
#ifndef __BMP180_H__
#define __BMP180_H__

/*!
* @brief The following definition uses for define the data types
*
* @note While porting the API please consider the following
* @note Please check the version of C standard
* @note Are you using Linux platform
*/

/*!
* @brief For the Linux platform support
* Please use the types.h for your data types definitions
*/
#ifdef	__KERNEL__

#include <linux/types.h>
/* singed integer type*/
typedef	int8_t s8;/**< used for signed 8bit */
typedef	int16_t s16;/**< used for signed 16bit */
typedef	int32_t s32;/**< used for signed 32bit */
typedef	int64_t s64;/**< used for signed 64bit */

typedef	u_int8_t u8;/**< used for unsigned 8bit */
typedef	u_int16_t u16;/**< used for unsigned 16bit */
typedef	u_int32_t u32;/**< used for unsigned 32bit */
typedef	u_int64_t u64;/**< used for unsigned 64bit */



#else /* ! __KERNEL__ */
/**********************************************************
* These definition uses for define the C
* standard version data types
***********************************************************/
# if !defined(__STDC_VERSION__)

/************************************************
 * compiler is C11 C standard
************************************************/
#if (__STDC_VERSION__ == 201112L)

/************************************************/
#include <stdint.h>
/************************************************/

/*unsigned integer types*/
typedef	uint8_t u8;/**< used for unsigned 8bit */
typedef	uint16_t u16;/**< used for unsigned 16bit */
typedef	uint32_t u32;/**< used for unsigned 32bit */
typedef	uint64_t u64;/**< used for unsigned 64bit */

/*signed integer types*/
typedef	int8_t s8;/**< used for signed 8bit */
typedef	int16_t s16;/**< used for signed 16bit */
typedef	int32_t s32;/**< used for signed 32bit */
typedef	int64_t s64;/**< used for signed 64bit */
/************************************************
 * compiler is C99 C standard
************************************************/

#elif (__STDC_VERSION__ == 199901L)

/* stdint.h is a C99 supported c library.
which is used to fixed the integer size*/
/************************************************/
#include <stdint.h>
/************************************************/

/*unsigned integer types*/
typedef	uint8_t u8;/**< used for unsigned 8bit */
typedef	uint16_t u16;/**< used for unsigned 16bit */
typedef	uint32_t u32;/**< used for unsigned 32bit */
typedef	uint64_t u64;/**< used for unsigned 64bit */

/*signed integer types*/
typedef int8_t s8;/**< used for signed 8bit */
typedef	int16_t s16;/**< used for signed 16bit */
typedef	int32_t s32;/**< used for signed 32bit */
typedef	int64_t s64;/**< used for signed 64bit */
/************************************************
 * compiler is C89 or other C standard
************************************************/

#else /*  !defined(__STDC_VERSION__) */
/*!
* @brief By default it is defined as 32 bit machine configuration
*	define your data types based on your
*	machine/compiler/controller configuration
*/
#define  MACHINE_32_BIT

/*! @brief
 *	If your machine support 16 bit
 *	define the MACHINE_16_BIT
 */
#ifdef MACHINE_16_BIT
#include <limits.h>
/*signed integer types*/
typedef	signed char  s8;/**< used for signed 8bit */
typedef	signed short int s16;/**< used for signed 16bit */
typedef	signed long int s32;/**< used for signed 32bit */

#if defined(LONG_MAX) && LONG_MAX == 0x7fffffffffffffffL
typedef long int s64;/**< used for signed 64bit */
typedef unsigned long int u64;/**< used for unsigned 64bit */
#elif defined(LLONG_MAX) && (LLONG_MAX == 0x7fffffffffffffffLL)
typedef long long int s64;/**< used for signed 64bit */
typedef unsigned long long int u64;/**< used for unsigned 64bit */
#else
#warning Either the correct data type for signed 64 bit integer \
could not be found, or 64 bit integers are not supported in your environment.
#warning If 64 bit integers are supported on your platform, \
please set s64 manually.
#endif

/*unsigned integer types*/
typedef	unsigned char u8;/**< used for unsigned 8bit */
typedef	unsigned short int u16;/**< used for unsigned 16bit */
typedef	unsigned long int u32;/**< used for unsigned 32bit */

/* If your machine support 32 bit
define the MACHINE_32_BIT*/
#elif defined MACHINE_32_BIT
/*signed integer types*/
typedef	signed char  s8;/**< used for signed 8bit */
typedef	signed short int s16;/**< used for signed 16bit */
typedef	signed int s32;/**< used for signed 32bit */
typedef	signed long long int s64;/**< used for signed 64bit */
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

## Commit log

2015-10-27 To avoid blank pull
    [EAS.EE.Part_Num_List.vbd2.xlsx, Sat_Cape.v7.brd, Sat_Cape.v7.sch]
2015-11-11 bmp180 baroSen(I2C_HW1_BUS_NUM);
2015-11-11 Add support for Honeywell HSC Sensors
2015-11-12 This is an indev init file for the RV12.
    DO NOT RUN BEFORE PERFORMING A BACKUP -- stability unconfirmed
    Reason for commit: backup
    Current purpose of files:
    EAS-RV12-Startup can be added to the boot script WITHOUT editing the uEnv.txt by:
    1). Copying the Script and associated files into "/etc/init.d" which places the file into the initialization folder
    2). Running the command "chmod +x /etc/init.d/EAS-RV12-Startup" which gives the file executeable status
    3). running the command "update-rc.d EAS-RV12-Startup defaults" which tells the system to try to execute the file at boot
    Script capabilities:
    1: logging messages to a custom file locatef in "/logs/*
    2: running multiple scripts via a func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
2015-11-19 Added Support for BME280 Pressure, Temperature, Humidity Sensor
2015-11-19 Changes to Source to support BME280 and fix /log missing hang, etc..
    [bmp180.cpp, eas_i2c_daq.cpp, mpu6050AccelGyro.cpp]
2016-02-05 gh-006
    I updated the init script to locate and execute any one file.
    The folder "testenv" may soon be deleted.
    Currently, the script will locate and execute "Enable_third_i2c.sh"
    WARNING: THIS CODE MAY NEED ERROR MANAGEMENT
    The code will also dump all console output into logs during the execution of it.
    As well as any logs you would typically see from the other scripts.
    These logs can be found in:
    "/logs/[filename].log"
    eg:
    file: "./Enable_third_i2c.sh"
    found at: "/logs/Enable_third_i2c.sh.log"
    Major edits made to vaiables to avoid reference collisions.
    Comments and test code need to be cleaned up, will do so next commit.
2016-02-05 gh-6 I updated the init script to locate and execute any one file. The folder "testenv" may soon be deleted.
    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
2016-02-06 Working Init Script gh-6
    I have officially gotten the init script to work.
    Apparently, my issue, as we discussed, was as simple as a bad directory call.
    This code executes a led sweep sequence on start-up ("EAS-RV12-Startup-Leds.sh") and then executes "Enable_third_i2c.sh"
    When shutting down, this code will flash all leds simultaneously for a while ("EAS-RV12-Shutdown-Leds.sh")
    The Led flashes are only used as debug code and are not inherently necessary.
    However, something you may be interested in knowing:
    THE SCRIPT WILL RUN WITHOUT LOGIN!
    This code takes about 4 minutes after boot to run because of the inherent slowness of the "find" command and the fact that I require the script to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
2016-02-16 new versions of sch/brd in /cape; added /docs
    [EAS.EE.Part_Num_List.vbd2.xlsx, Sat_Cape.v7.brd, Sat_Cape.v7.sch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]
2016-02-29 recover after forced push
    [EAS.EE.Part_Num_List.vbd2.xlsx, Sat_Cape.v8.brd, Sat_Cape.v8.sch]
2016-02-29 Delete EAS.EE.Part_Num_List.vbd2.xlsx
    Moved to /docs
    [EAS.EE.Part_Num_List.vbd2.xlsx]
2016-02-29 Delete Sat_Cape.v7.brd
    Old Version
    [Sat_Cape.v7.brd]
2016-02-29 Delete Sat_Cape.v7.sch
    Old version
    [Sat_Cape.v7.sch]
2016-03-02 added logfile Part A Sensor ID info
    [EAS.EE.Part_Num_List.vbd2.xlsx, Sat_Cape.v8.brd, Sat_Cape.v8.sch]
2016-03-14 Added Analog Cape v9 from BBB
    [Sat_Cape.v9.brd, Sat_Cape.v9.sch]
2016-09-23 From Office code
    [Sat_Cape.v8.brd, Sat_Cape.v8.sch]
2017-09-25 Delete gpsCOMM.cpp
    This file has been cut up into several pieces to increase readability.
2017-10-23 Update readme.md to mention proper sensor type.
2018-09-28 Initial six pack design
    Rev 1A for the EAS six pack design.
    [6packRev1A.brd, 6packRev1A.sch]
2018-09-28 Cape Complete redesign
    Matt's Complete redesign for the cape
    [EASCapeRev1A.brd, EASCapeRev1A.sch]
2018-09-28 Cape Fixes
    Update outline for the cape around the ethernet port cutout so that it will be cut out. Move the top of the cape, creating more space for the rj45 jacks.
    [EASCapeRev2A.brd, EASCapeRev2A.sch]
2018-10-01 Breate rev 1B for six pack
    Create new revision of six pack fixing spacing and pinout issues.
    [6packRev1B.brd, 6packRev1B.sch]
2018-10-01 Make test cape more compact
    [6packRev1B.brd]
2018-10-01 Cape 1B try 2
    [6packRev1B.brd, 6packRev1B.sch]
2018-10-09 6 pack version 1C
    [6packRev1C.brd, 6packRev1C.sch]
2018-10-22 6Pack 1D
    [6packRev1D.brd, 6packRev1D.sch]
2018-10-24 6Pack version 2A
    [6packRev2A.brd, 6packRev2A.sch]
2018-10-26 Update 6Pack 2A
    [6packRev2A.brd, 6packRev2A.sch]
2018-10-26 Revert "Update 6Pack 2A"
    This reverts commit 827b5304b12bda17fe1987ea76be93996f945791.
    [6packRev2A.brd, 6packRev2A.sch]
2018-10-26 Crete 6Pack Rev 3A
    Fixes issue in rev 2A where resistors were pulling down instead of pulling up.
    [6packRev3A.brd, 6packRev3A.sch]
2018-10-26 Fix footprint cape 3A
    [6packRev3A.brd, 6packRev3A.sch]

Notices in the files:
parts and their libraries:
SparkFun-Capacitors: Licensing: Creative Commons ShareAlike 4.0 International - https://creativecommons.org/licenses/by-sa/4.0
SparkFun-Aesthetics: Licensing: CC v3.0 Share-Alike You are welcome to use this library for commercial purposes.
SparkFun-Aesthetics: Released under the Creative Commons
